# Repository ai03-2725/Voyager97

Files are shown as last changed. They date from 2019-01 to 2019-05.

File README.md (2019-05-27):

# Voyager97
A versatile, modern full-functionality keyboard PCB

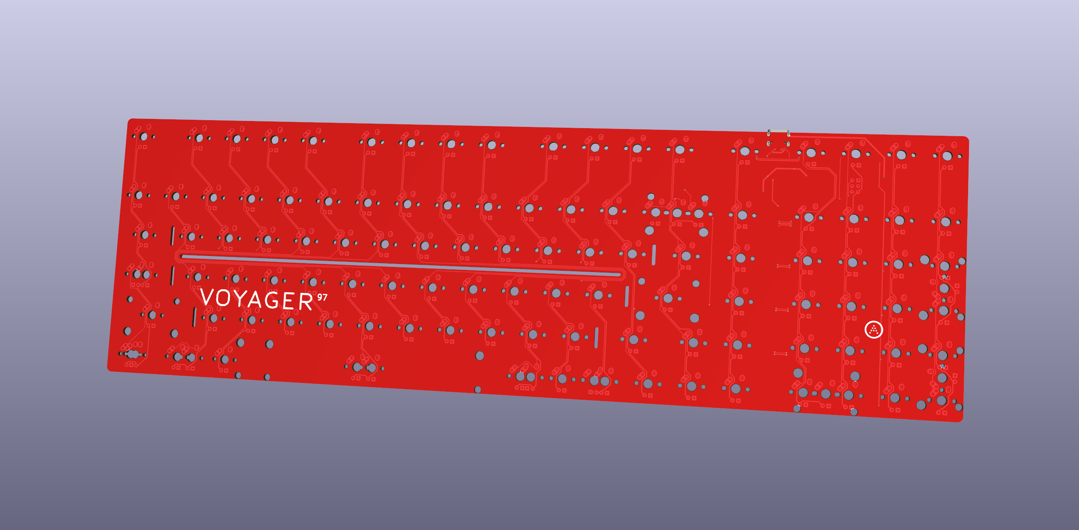
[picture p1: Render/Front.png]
Render

[PCB Layout](http://www.keyboard-layout-editor.com/#/gists/8a6f76a9ac2c94977268a77ed8a0af57)

#### In light of recent claims that I am 100% liable for any of my open source PCBs, I am adding this disclaimer.
#### I provide these PCBs as a reference for designing keyboard PCBs. Using them within your projects will require a will to do research of one's own and to learn the workings of them, potentially fixing issues if they exist.
# I provide these PCBs without liability and without any guarantees regarding functionality, as expressed in the MIT license under which all of these PCBs are licensed.

### Features
* In-switch LED backlighting
* RGB underglow
* Flex slot cutout for typing comfort
* Decent amount of layout compatibility
* Over-current and static discharge protection
* Fully open-source

### The Voyager PCB Family
The Voyager PCBs offer fully featured PCBs fit for any keyboard, whether mass production or high-end.

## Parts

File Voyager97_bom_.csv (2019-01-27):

Component | Description | Part | References | Value | Footprint | Quantity Per PCB | Datasheet | Field8 | Field4 | Field7 | Field6 | Field5
1 |  | MX-1U | BS1-2 BS2 MX_#0_1 MX_#1 MX_#2 MX_#3 MX_#4 MX_#5 MX_#6 MX_#7 MX_#8 MX_#9 MX_'1 MX_,1 MX_-1 MX_.1 MX_/1 MX_;1 MX_=1 MX_A1 MX_B1 MX_C1 MX_D1 MX_DOWN1 MX_E1 MX_ESC1 MX_EX1 MX_EX2 MX_EX3 MX_EX4 MX_F1 MX_FN1 MX_FN2 MX_FN3 MX_FN4 MX_FN5 MX_FN6 MX_FN7 MX_FN8 MX_FN9 MX_FN10 MX_FN11 MX_FN12 MX_G1 MX_H1 MX_I1 MX_J1 MX_K1 MX_L1 MX_LEFT1 MX_M1 MX_N1 MX_NUM1 MX_NUM2 MX_NUM3 MX_NUM4 MX_NUM5 MX_NUM6 MX_NUM7 MX_NUM8 MX_NUM9 MX_NUM10 MX_NUM11 MX_NUM12 MX_NUM13 MX_NUM14 MX_NUM15 MX_NUM16 MX_NUM17 MX_NUM18 MX_NUM19 MX_NUM20 MX_NUM21 MX_NUM22 MX_NUM23 MX_NUM24 MX_O1 MX_P1 MX_Q1 MX_R1 MX_RESET1 MX_RIGHT1 MX_S1 MX_T1 MX_U1 MX_UP1 MX_V1 MX_W1 MX_X1 MX_Y1 MX_Z1 MX_[1 MX_]1 MX_`1 | MX-1U | MX-1U | 94
2 |  | MX-2U | BS1-1 | MX-2U | MX-2U | 1
3 | Unpolarized capacitor | C_Small | C6 C7 C8 | 0.1uF | C_0603 | 3
4 | Unpolarized capacitor | C_Small | C2 C5 | 1uF | C_0603 | 2
5 | Unpolarized capacitor | C_Small | C3 C4 | 22pF | C_0603 | 2
6 |  | MX-1.25U | CL1-2 | MX-1.25U | MX-1.25U-FLIPPED | 1
7 |  | MX-1.75U | CL1-1 | MX-1.75U | MX-1.75U | 1
8 | Diode, small symbol | D_Small | D1 D2 D3 D4 D5 D6 D7 D8 D9 D10 D11 D12 D13 D14 D15 D16 D17 D18 D19 D20 D21 D22 D23 D24 D25 D26 D27 D28 D29 D30 D31 D32 D33 D35 D36 D37 D38 D39 D40 D41 D42 D43 D44 D45 D46 D47 D48 D52 D53 D54 D55 D56 D57 D58 D59 D60 D61 D62 D63 D65 D66 D67 D68 D69 D70 D71 D72 D73 D74 D75 D76 D77 D78 D80 D81 D82 D83 D84 D85 D86 D87 D89 D90 D91 D92 D93 D94 D95 D96 D97 D98 D99 D100 D101 D102 D103 D104 D105 D106 D107 D108 D109 D110 D111 D112 D113 D114 | SOD-323 | D_SOD-123 | 107
9 | resettable fuse, polymeric positive temperature coefficient (PPTC), small symbol | Polyfuse_Small | F1 | 500mA | Fuse_SMD1206_Reflow | 1
10 | Atmel 6-pin ISP connector | AVR-ISP-6 | J1 | AVR-ISP-6 | Reset_Pretty-Mask | 1 | ~
11 |  | MX-1U | LM1-1 | MX-1.25U | MX-1.25U | 1
12 |  | MX-1.25U | LM2-1 LM3-1 | MX-1.25U | MX-1.25U | 2
13 |  | MX-1.5U | LM1-2 RM1-2 RM3-2 | MX-1.5U | MX-1.5U-FLIPPED | 3
14 |  | MX-1.5U | LM3-2 MX_TAB1 MX_\1 | MX-1.5U | MX-1.5U | 3
15 |  | MX-2.25U | LS1-1 MX_RETURN1 | MX-2.25U | MX-2.25U | 2
16 |  | MX-1U | MX_RSHIFT1 | MX-1.75U | MX-1.75U | 1
17 |  | MX-1U | MX_NUMEXT2 MX_NUMEXT4 MX_NUMEXT5 | MX-2U | MX-2U-ReversedStabilizers | 3
18 | Transistor NPN (general) | Q_NPN_BCE | Q1 | DSS60601MZ4-13 | SOT-223-3_TabPin2 | 1
19 | Resistor, small symbol | R_Small | R1 R2 R3 R4 R5 R6 R7 R8 R9 R10 R11 R12 R13 R14 R15 R16 R17 R18 R19 R20 R21 R22 R23 R24 R25 R26 R27 R28 R29 R30 R31 R32 R33 R34 R35 R36 R37 R38 R39 R40 R41 R42 R43 R44 R45 R46 R47 R48 R49 R50 R52 R53 R54 R55 R56 R57 R58 R59 R60 R61 R62 R63 R65 R66 R67 R68 R69 R70 R71 R72 R73 R74 R75 R76 R77 R78 R80 R81 R82 R83 R84 R85 R86 R87 R89 R90 R91 R95 R96 R97 R98 R99 R100 R101 R102 R103 R104 R105 R106 R107 R108 R109 R110 R111 R112 R113 R114 RC4 | 1k | R_0603 | 108
20 | Resistor, small symbol | R_Small | RC5 | 1.5k | R_0603 | 1
21 | Resistor, small symbol | R_Small | RC3 | 10k | R_0603 | 1
22 | Resistor, small symbol | R_Small | RC1 RC2 | 22 | R_0603 | 2
23 | Resistor, small symbol | R_Small | RC6 RC7 | 5k1 | R_0603 | 2
24 |  | MX-1.25U | RM1-1 RM2-1 RM3-1 | MX-1U | MX-1U | 3
25 |  | MX-6.25U | SP1 | MX-6.25U | MX-6.25U-ReversedStabilizers | 1
26 |  | MX-7U | SP2 | MX-7U | MX-7U-ReversedStabilizers | 1
27 | Push button switch, generic, two pins | SW_Push | SW1 | SW_Push | SKQG-1155865 | 1
28 | 16MHz, 64kB Flash, 4kB SRAM, 2kB EEPROM, USB 2.0, QFN-64 | AT90USB1286-MU | U1 | AT90USB1286-AU | QFN-64-1EP_9x9mm_Pitch0.5mm | 1 | 8.69 USD | AT90USB1286-AU | TQFP-64 Microchip | Good | Embedded microcontroller AT90USB1286-AU TQFP 64 _14x14_ Microchip Technology 8-Bit 16 MHz I/O number 48 | Microchip
29 |  | PRTR5V0U2X | U2 | PRTR5V0U2X | SOT143B | 1
30 |  | HRO-TYPE-C-31-M-12 | USB1 | HRO-TYPE-C-31-M-12 | HRO-TYPE-C-31-M-12-Assembly | 1
31 | Four pin crystal (GND on pins 2 and 4), e.g. in SMD package | Crystal_GND24 | Y1 | 16MHz | Crystal_SMD_3225-4pin_3.2x2.5mm | 1
Component Groups: | 31
Component Count: | 353
Fitted Components: | 353
Number of PCBs: | 1
Total components: | 353
Schematic Version:
Schematic Date:
BoM Date: | 1/27/2019 3:01
Schematic Source:
KiCad Version: | Eeschema (5.0.0)

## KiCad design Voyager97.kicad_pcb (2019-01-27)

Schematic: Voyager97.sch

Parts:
C2, C5: 1uF; C_0603
C3, C4: 22pF; C_0603
C6, C7, C8: 0.1uF; C_0603
F1: 500mA; Fuse_SMD1206_Reflow
J1: AVR-ISP-6; Reset_Pretty-Mask
Q1: DSS60601MZ4-13; SOT-223-3_TabPin2
RC1, RC2: 22; R_0603
RC3: 10k; R_0603
RC4: 1k; R_0603
RC5: 1.5k; R_0603
RC6, RC7: 5k1; R_0603
SW1: SW_Push; SKQG-1155865
U1: AT90USB1286-AU; QFN-64-1EP_9x9mm_Pitch0.5mm
U2: PRTR5V0U2X; SOT143B
USB1: HRO-TYPE-C-31-M-12; HRO-TYPE-C-31-M-12-Assembly
Y1: 16MHz; Crystal_SMD_3225-4pin_3.2x2.5mm

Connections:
COL0: U1.61 (PF0); also elsewhere on the board
COL1: U1.60 (PF1); also elsewhere on the board
COL2: U1.59 (PF2); also elsewhere on the board
COL3: U1.58 (PF3); also elsewhere on the board
COL4: U1.57 (PF4); also elsewhere on the board
COL5: U1.56 (PF5); also elsewhere on the board
COL6: U1.55 (PF6); also elsewhere on the board
COL7: U1.54 (PF7); also elsewhere on the board
COL8: U1.51 (PA0); also elsewhere on the board
COL9: U1.50 (PA1); also elsewhere on the board
COL10: U1.49 (PA2); also elsewhere on the board
COL11: U1.48 (PA3); also elsewhere on the board
COL12: U1.47 (PA4); also elsewhere on the board
COL13: U1.46 (PA5); also elsewhere on the board
COL14: U1.45 (PA6); also elsewhere on the board
COL15: U1.36 (PC1); also elsewhere on the board
COL16: U1.35 (PC0); also elsewhere on the board
COL17: U1.34 (PE1); also elsewhere on the board
COL18: U1.33 (PE0); also elsewhere on the board
D+: RC2.2, U1.5 (D+)
D-: RC1.1, U1.4 (D-)
GND: C2.2, C3.2, C4.2, C5.1, C6.1, C7.1, C8.1, J1.6, Q1.3, RC4.2, RC6.1, RC7.1, SW1.1, U1.6 (UGND), U1.22 (GND), U1.53 (GND), U1.63 (GND), U1.65 (GND), U2.1, USB1.1, USB1.12, USB1.13, Y1.2, Y1.4
LEDGND: Q1.2; also elsewhere on the board
MISO: J1.1, U1.13 (PB3)
MOSI: J1.4, U1.12 (PB2)
unnamed: C2.1, U1.7 (UCAP)
unnamed: Q1.1, RC5.2
unnamed: RC1.2, U2.3, USB1.5, USB1.7
unnamed: RC2.1, U2.2, USB1.6, USB1.8
unnamed: RC4.1, U1.43 (PE2/~HWB)
unnamed: RC5.1, U1.17 (PB7)
unnamed: RC6.2, USB1.4
unnamed: RC7.2, USB1.10
RESET: J1.5, RC3.2, SW1.2, U1.20 (~RESET)
ROW0: U1.32 (PD7); also elsewhere on the board
ROW1: U1.38 (PC3); also elsewhere on the board
ROW2: U1.39 (PC4); also elsewhere on the board
ROW3: U1.40 (PC5); also elsewhere on the board
ROW4: U1.41 (PC6); also elsewhere on the board
ROW5: U1.42 (PC7); also elsewhere on the board
SCK: J1.3, U1.11 (PB1)
VCC: F1.2, U2.4, USB1.2, USB1.11
XTAL1: C3.1, U1.24 (XTAL1), Y1.1
XTAL2: C4.1, U1.23 (XTAL2), Y1.3

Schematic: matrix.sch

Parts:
BS1-1: MX-2U
BS1-2, BS2: MX-1U
CL1-1: MX-1.75U
CL1-2: MX-1.25U; MX-1.25U-FLIPPED
D1, D2, D3, D4, D5, D6, D7, D8, D9, D10, D11, D12, D13, D14, D15, D16, D17, D18, D19, D20, D21, D22, D23, D24, D25, D26, D27, D28, D29, D30, D31, D32, D33, D35, D36, D37, D38, D39, D40, D41, D42, D43, D44, D45, D46, D47, D48, D52, D53, D54, D55, D56, D57, D58, D59, D60, D61, D62, D63, D65, D66, D67, D68, D69, D70, D71, D72, D73, D74, D75, D76, D77, D78, D80, D81, D82, D83, D84, D85, D86, D87, D89, D90, D91, D92, D93, D94, D95, D96, D97, D98, D99, D100, D101, D102, D103, D104, D105, D106, D107, D108, D109, D110, D111, D112, D113, D114: SOD-323; D_SOD-123
LM1-1, LM2-1, LM3-1: MX-1.25U
LM1-2: MX-1.5U; MX-1.5U-FLIPPED
LM3-2: MX-1.5U
LS1-1: MX-2.25U
MX_#0_1, MX_#1, MX_#2, MX_#3, MX_#4, MX_#5, MX_#6, MX_#7, MX_#8, MX_#9: MX-1U
MX_'1: MX-1U
MX_,1: MX-1U
MX_-1: MX-1U
MX_.1: MX-1U
MX_/1: MX-1U
MX_;1: MX-1U
MX_=1: MX-1U
MX_A1: MX-1U
MX_B1: MX-1U
MX_C1: MX-1U
MX_D1: MX-1U
MX_DOWN1: MX-1U
MX_E1: MX-1U
MX_ESC1: MX-1U
MX_EX1, MX_EX2, MX_EX3, MX_EX4: MX-1U
MX_F1: MX-1U
MX_FN1, MX_FN2, MX_FN3, MX_FN4, MX_FN5, MX_FN6, MX_FN7, MX_FN8, MX_FN9, MX_FN10, MX_FN11, MX_FN12: MX-1U
MX_G1: MX-1U
MX_H1: MX-1U
MX_I1: MX-1U
MX_J1: MX-1U
MX_K1: MX-1U
MX_L1: MX-1U
MX_LEFT1: MX-1U
MX_M1: MX-1U
MX_N1: MX-1U
MX_NUM1, MX_NUM2, MX_NUM3, MX_NUM4, MX_NUM5, MX_NUM6, MX_NUM7, MX_NUM8, MX_NUM9, MX_NUM10, MX_NUM11, MX_NUM12, MX_NUM13, MX_NUM14, MX_NUM15, MX_NUM16, MX_NUM17, MX_NUM18, MX_NUM19, MX_NUM20, MX_NUM21, MX_NUM22, MX_NUM23, MX_NUM24: MX-1U
MX_NUMEXT2, MX_NUMEXT4, MX_NUMEXT5: MX-2U; MX-2U-ReversedStabilizers
MX_O1: MX-1U
MX_P1: MX-1U
MX_Q1: MX-1U
MX_R1: MX-1U
MX_RESET1: MX-1U
MX_RETURN1: MX-2.25U
MX_RIGHT1: MX-1U
MX_RSHIFT1: MX-1.75U
MX_S1: MX-1U
MX_T1: MX-1U
MX_TAB1: MX-1.5U
MX_U1: MX-1U
MX_UP1: MX-1U
MX_V1: MX-1U
MX_W1: MX-1U
MX_X1: MX-1U
MX_Y1: MX-1U
MX_Z1: MX-1U
MX_[1: MX-1U
MX_\1: MX-1.5U
MX_]1: MX-1U
MX_`1: MX-1U
R1, R2, R3, R4, R5, R6, R7, R8, R9, R10, R11, R12, R13, R14, R15, R16, R17, R18, R19, R20, R21, R22, R23, R24, R25, R26, R27, R28, R29, R30, R31, R32, R33, R34, R35, R36, R37, R38, R39, R40, R41, R42, R43, R44, R45, R46, R47, R48, R49, R50, R52, R53, R54, R55, R56, R57, R58, R59, R60, R61, R62, R63, R65, R66, R67, R68, R69, R70, R71, R72, R73, R74, R75, R76, R77, R78, R80, R81, R82, R83, R84, R85, R86, R87, R89, R90, R91, R95, R96, R97, R98, R99, R100, R101, R102, R103, R104, R105, R106, R107, R108, R109, R110, R111, R112, R113, R114: 1k; R_0603
RM1-1, RM2-1, RM3-1: MX-1U
RM1-2, RM3-2: MX-1.5U; MX-1.5U-FLIPPED
SP1: MX-6.25U; MX-6.25U-ReversedStabilizers
SP2: MX-7U; MX-7U-ReversedStabilizers

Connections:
COL0: CL1-1.1, CL1-2.2, LM1-1.1, LM1-2.1, LS1-1.1, MX_ESC1.1, MX_TAB1.1, MX_`1.1; also elsewhere on the board
COL1: LM2-1.1, LM3-2.2, MX_#1.1, MX_A1.1, MX_Q1.1, MX_Z1.1; also elsewhere on the board
COL2: LM3-1.1, MX_#2.1, MX_FN1.1, MX_S1.1, MX_W1.1, MX_X1.1; also elsewhere on the board
COL3: MX_#3.1, MX_C1.1, MX_D1.1, MX_E1.1, MX_FN2.1; also elsewhere on the board
COL4: MX_#4.1, MX_F1.1, MX_FN3.1, MX_R1.1, MX_V1.1; also elsewhere on the board
COL5: MX_#5.1, MX_B1.1, MX_FN4.1, MX_G1.1, MX_T1.1, SP1.1, SP2.2; also elsewhere on the board
COL6: MX_#6.1, MX_FN5.1, MX_H1.1, MX_N1.1, MX_Y1.1; also elsewhere on the board
COL7: MX_#7.1, MX_FN6.1, MX_J1.1, MX_M1.1, MX_U1.1; also elsewhere on the board
COL8: MX_#8.1, MX_,1.1, MX_FN7.1, MX_I1.1, MX_K1.1; also elsewhere on the board
COL9: MX_#9.1, MX_.1.1, MX_FN8.1, MX_L1.1, MX_O1.1, RM1-1.1, RM1-2.2; also elsewhere on the board
COL10: MX_#0_1.1, MX_/1.1, MX_;1.1, MX_FN9.1, MX_P1.1, RM2-1.1; also elsewhere on the board
COL11: MX_'1.1, MX_-1.1, MX_FN10.1, MX_[1.1, RM3-1.1, RM3-2.2; also elsewhere on the board
COL12: BS2.1, MX_=1.1, MX_FN11.1, MX_LEFT1.1, MX_RSHIFT1.1, MX_]1.1; also elsewhere on the board
COL13: BS1-1.1, BS1-2.1, MX_DOWN1.1, MX_FN12.1, MX_RETURN1.1, MX_UP1.1, MX_\1.1; also elsewhere on the board
COL14: MX_EX1.1, MX_EX2.1, MX_EX3.1, MX_EX4.1, MX_RESET1.1, MX_RIGHT1.1; also elsewhere on the board
COL15: MX_NUM1.1, MX_NUM4.1, MX_NUM8.1, MX_NUM12.1, MX_NUM16.1, MX_NUM20.1, MX_NUMEXT5.1; also elsewhere on the board
COL16: MX_NUM2.1, MX_NUM5.1, MX_NUM9.1, MX_NUM13.1, MX_NUM17.1, MX_NUM21.1; also elsewhere on the board
COL17: MX_NUM3.1, MX_NUM6.1, MX_NUM10.1, MX_NUM14.1, MX_NUM18.1, MX_NUM22.1; also elsewhere on the board
COL18: MX_NUM7.1, MX_NUM11.1, MX_NUM15.1, MX_NUM19.1, MX_NUM23.1, MX_NUM24.1, MX_NUMEXT2.1, MX_NUMEXT4.1; also elsewhere on the board
LEDGND: R1.2, R2.2, R3.2, R4.2, R5.2, R6.2, R7.2, R8.2, R9.2, R10.2, R11.2, R12.2, R13.2, R14.2, R15.2, R16.2, R17.2, R18.2, R19.2, R20.2, R21.2, R22.2, R23.2, R24.2, R25.2, R26.2, R27.2, R28.2, R29.2, R30.2, R31.2, R32.2, R33.2, R34.2, R35.2, R36.2, R37.2, R38.2, R39.2, R40.2, R41.2, R42.2, R43.2, R44.2, R45.2, R46.2, R47.2, R48.2, R49.2, R50.2, R52.2, R53.2, R54.2, R55.2, R56.2, R57.2, R58.2, R59.2, R60.2, R61.2, R62.2, R63.2, R65.2, R66.2, R67.2, R68.2, R69.2, R70.2, R71.2, R72.2, R73.2, R74.2, R75.2, R76.2, R77.2, R78.2, R80.2, R81.2, R82.2, R83.2, R84.2, R85.2, R86.2, R87.2, R89.2, R90.2, R91.2, R95.2, R96.2, R97.2, R98.2, R99.2, R100.2, R101.2, R102.2, R103.2, R104.2, R105.2, R106.2, R107.2, R108.2, R109.2, R110.2, R111.2, R112.2, R113.2, R114.2; also elsewhere on the board
unnamed: BS1-1.2, BS1-2.2, D30.2
unnamed: BS1-1.4, BS1-2.4, R30.1
unnamed: BS2.2, D31.2
unnamed: BS2.4, R31.1
unnamed: CL1-1.2, CL1-2.1, D52.2
unnamed: CL1-1.4, CL1-2.4, R52.1
unnamed: D1.2, MX_ESC1.2
unnamed: D2.2, MX_FN1.2
unnamed: D3.2, MX_FN2.2
unnamed: D4.2, MX_FN3.2
unnamed: D5.2, MX_FN4.2
unnamed: D6.2, MX_FN5.2
unnamed: D7.2, MX_FN6.2
unnamed: D8.2, MX_FN7.2
unnamed: D9.2, MX_FN8.2
unnamed: D10.2, MX_FN9.2
unnamed: D11.2, MX_FN10.2
unnamed: D12.2, MX_FN11.2
unnamed: D13.2, MX_FN12.2
unnamed: D14.2, MX_EX1.2
unnamed: D15.2, MX_RESET1.2
unnamed: D16.2, MX_NUM24.2
unnamed: D17.2, MX_`1.2
unnamed: D18.2, MX_#1.2
unnamed: D19.2, MX_#2.2
unnamed: D20.2, MX_#3.2
unnamed: D21.2, MX_#4.2
unnamed: D22.2, MX_#5.2
unnamed: D23.2, MX_#6.2
unnamed: D24.2, MX_#7.2
unnamed: D25.2, MX_#8.2
unnamed: D26.2, MX_#9.2
unnamed: D27.2, MX_#0_1.2
unnamed: D28.2, MX_-1.2
unnamed: D29.2, MX_=1.2
unnamed: D32.2, MX_EX2.2
unnamed: D33.2, MX_EX3.2
unnamed: D35.2, MX_TAB1.2
unnamed: D36.2, MX_Q1.2
unnamed: D37.2, MX_W1.2
unnamed: D38.2, MX_E1.2
unnamed: D39.2, MX_R1.2
unnamed: D40.2, MX_T1.2
unnamed: D41.2, MX_Y1.2
unnamed: D42.2, MX_U1.2
unnamed: D43.2, MX_I1.2
unnamed: D44.2, MX_O1.2
unnamed: D45.2, MX_P1.2
unnamed: D46.2, MX_[1.2
unnamed: D47.2, MX_]1.2
unnamed: D48.2, MX_\1.2
unnamed: D53.2, MX_A1.2
unnamed: D54.2, MX_S1.2
unnamed: D55.2, MX_D1.2
unnamed: D56.2, MX_F1.2
unnamed: D57.2, MX_G1.2
unnamed: D58.2, MX_H1.2
unnamed: D59.2, MX_J1.2
unnamed: D60.2, MX_K1.2
unnamed: D61.2, MX_L1.2
unnamed: D62.2, MX_;1.2
unnamed: D63.2, MX_'1.2
unnamed: D65.2, MX_RETURN1.2
unnamed: D66.2, MX_UP1.2
unnamed: D67.2, LS1-1.2
unnamed: D68.2, MX_Z1.2
unnamed: D69.2, MX_X1.2
unnamed: D70.2, MX_C1.2
unnamed: D71.2, MX_V1.2
unnamed: D72.2, MX_B1.2
unnamed: D73.2, MX_N1.2
unnamed: D74.2, MX_M1.2
unnamed: D75.2, MX_,1.2
unnamed: D76.2, MX_.1.2
unnamed: D77.2, MX_/1.2
unnamed: D78.2, MX_RSHIFT1.2
unnamed: D80.2, MX_EX4.2
unnamed: D81.2, MX_LEFT1.2
unnamed: D82.2, MX_DOWN1.2
unnamed: D83.2, MX_RIGHT1.2
unnamed: D84.2, LM1-1.2, LM1-2.2
unnamed: D85.2, LM2-1.2, LM3-2.1
unnamed: D86.2, LM3-1.2
unnamed: D87.2, SP1.2, SP2.1
unnamed: D89.2, RM1-1.2, RM1-2.1
unnamed: D90.2, RM2-1.2
unnamed: D91.2, RM3-1.2, RM3-2.1
unnamed: D92.2, MX_NUM1.2
unnamed: D93.2, MX_NUM2.2
unnamed: D94.2, MX_NUM3.2
unnamed: D95.2, MX_NUM4.2
unnamed: D96.2, MX_NUM5.2
unnamed: D97.2, MX_NUM6.2
unnamed: D98.2, MX_NUM7.2
unnamed: D99.2, MX_NUM8.2
unnamed: D100.2, MX_NUM9.2
unnamed: D101.2, MX_NUM10.2
unnamed: D102.2, MX_NUM11.2, MX_NUMEXT2.2
unnamed: D103.2, MX_NUM12.2
unnamed: D104.2, MX_NUM13.2
unnamed: D105.2, MX_NUM14.2
unnamed: D106.2, MX_NUM15.2
unnamed: D107.2, MX_NUM16.2
unnamed: D108.2, MX_NUM17.2
unnamed: D109.2, MX_NUM18.2
unnamed: D110.2, MX_NUM19.2, MX_NUMEXT4.2
unnamed: D111.2, MX_NUM20.2, MX_NUMEXT5.2
unnamed: D112.2, MX_NUM21.2
unnamed: D113.2, MX_NUM22.2
unnamed: D114.2, MX_NUM23.2
unnamed: LM1-1.4, LM1-2.4, R84.1
unnamed: LM2-1.4, LM3-2.4, R85.1
unnamed: LM3-1.4, R86.1
unnamed: LS1-1.4, R67.1
unnamed: MX_#0_1.4, R27.1
unnamed: MX_#1.4, R18.1
unnamed: MX_#2.4, R19.1
unnamed: MX_#3.4, R20.1
unnamed: MX_#4.4, R21.1
unnamed: MX_#5.4, R22.1
unnamed: MX_#6.4, R23.1
unnamed: MX_#7.4, R24.1
unnamed: MX_#8.4, R25.1
unnamed: MX_#9.4, R26.1
unnamed: MX_'1.4, R63.1
unnamed: MX_,1.4, R75.1
unnamed: MX_-1.4, R28.1
unnamed: MX_.1.4, R76.1
unnamed: MX_/1.4, R77.1
unnamed: MX_;1.4, R62.1
unnamed: MX_=1.4, R29.1
unnamed: MX_A1.4, R53.1
unnamed: MX_B1.4, R72.1
unnamed: MX_C1.4, R70.1
unnamed: MX_D1.4, R55.1
unnamed: MX_DOWN1.4, R82.1
unnamed: MX_E1.4, R38.1
unnamed: MX_ESC1.4, R1.1
unnamed: MX_EX1.4, R14.1
unnamed: MX_EX2.4, R49.1
unnamed: MX_EX3.4, R50.1
unnamed: MX_EX4.4, R80.1
unnamed: MX_F1.4, R56.1
unnamed: MX_FN1.4, R2.1
unnamed: MX_FN2.4, R3.1
unnamed: MX_FN3.4, R4.1
unnamed: MX_FN4.4, R5.1
unnamed: MX_FN5.4, R6.1
unnamed: MX_FN6.4, R7.1
unnamed: MX_FN7.4, R8.1
unnamed: MX_FN8.4, R9.1
unnamed: MX_FN9.4, R10.1
unnamed: MX_FN10.4, R11.1
unnamed: MX_FN11.4, R12.1
unnamed: MX_FN12.4, R13.1
unnamed: MX_G1.4, R57.1
unnamed: MX_H1.4, R58.1
unnamed: MX_I1.4, R43.1
unnamed: MX_J1.4, R59.1
unnamed: MX_K1.4, R60.1
unnamed: MX_L1.4, R61.1
unnamed: MX_LEFT1.4, R81.1
unnamed: MX_M1.4, R74.1
unnamed: MX_N1.4, R73.1
unnamed: MX_NUM1.4, R16.1
unnamed: MX_NUM2.4, R32.1
unnamed: MX_NUM3.4, R33.1
unnamed: MX_NUM4.4, R95.1
unnamed: MX_NUM5.4, R96.1
unnamed: MX_NUM6.4, R97.1
unnamed: MX_NUM7.4, R98.1
unnamed: MX_NUM8.4, R99.1
unnamed: MX_NUM9.4, R100.1
unnamed: MX_NUM10.4, R101.1
unnamed: MX_NUM11.4, MX_NUMEXT2.4, R102.1
unnamed: MX_NUM12.4, R103.1
unnamed: MX_NUM13.4, R104.1
unnamed: MX_NUM14.4, R105.1
unnamed: MX_NUM15.4, R106.1
unnamed: MX_NUM16.4, R107.1
unnamed: MX_NUM17.4, R108.1
unnamed: MX_NUM18.4, R109.1
unnamed: MX_NUM19.4, MX_NUMEXT4.4, R110.1
unnamed: MX_NUM20.4, MX_NUMEXT5.4, R111.1
unnamed: MX_NUM21.4, R112.1
unnamed: MX_NUM22.4, R113.1
unnamed: MX_NUM23.4, R114.1
unnamed: MX_NUM24.4, R34.1
unnamed: MX_O1.4, R44.1
unnamed: MX_P1.4, R45.1
unnamed: MX_Q1.4, R36.1
unnamed: MX_R1.4, R39.1
unnamed: MX_RESET1.4, R15.1
unnamed: MX_RETURN1.4, R65.1
unnamed: MX_RIGHT1.4, R83.1
unnamed: MX_RSHIFT1.4, R78.1
unnamed: MX_S1.4, R54.1
unnamed: MX_T1.4, R40.1
unnamed: MX_TAB1.4, R35.1
unnamed: MX_U1.4, R42.1
unnamed: MX_UP1.4, R66.1
unnamed: MX_V1.4, R71.1
unnamed: MX_W1.4, R37.1
unnamed: MX_X1.4, R69.1
unnamed: MX_Y1.4, R41.1
unnamed: MX_Z1.4, R68.1
unnamed: MX_[1.4, R46.1
unnamed: MX_\1.4, R48.1
unnamed: MX_]1.4, R47.1
unnamed: MX_`1.4, R17.1
unnamed: R87.1, SP1.4, SP2.4
unnamed: R89.1, RM1-1.4, RM1-2.4
unnamed: R90.1, RM2-1.4
unnamed: R91.1, RM3-1.4, RM3-2.4
ROW0: D1.1, D2.1, D3.1, D4.1, D5.1, D6.1, D7.1, D8.1, D9.1, D10.1, D11.1, D12.1, D13.1, D15.1, D16.1, D92.1, D93.1, D94.1; also elsewhere on the board
ROW1: D14.1, D17.1, D18.1, D19.1, D20.1, D21.1, D22.1, D23.1, D24.1, D25.1, D26.1, D27.1, D28.1, D29.1, D30.1, D95.1, D96.1, D97.1, D98.1; also elsewhere on the board
ROW2: D32.1, D35.1, D36.1, D37.1, D38.1, D39.1, D40.1, D41.1, D42.1, D43.1, D44.1, D45.1, D46.1, D47.1, D48.1, D99.1, D100.1, D101.1, D102.1; also elsewhere on the board
ROW3: D31.1, D33.1, D52.1, D53.1, D54.1, D55.1, D56.1, D57.1, D58.1, D59.1, D60.1, D61.1, D62.1, D63.1, D65.1, D103.1, D104.1, D105.1, D106.1; also elsewhere on the board
ROW4: D66.1, D67.1, D68.1, D69.1, D70.1, D71.1, D72.1, D73.1, D74.1, D75.1, D76.1, D77.1, D78.1, D80.1, D107.1, D108.1, D109.1, D110.1; also elsewhere on the board
ROW5: D81.1, D82.1, D83.1, D84.1, D85.1, D86.1, D87.1, D89.1, D90.1, D91.1, D111.1, D112.1, D113.1, D114.1; also elsewhere on the board

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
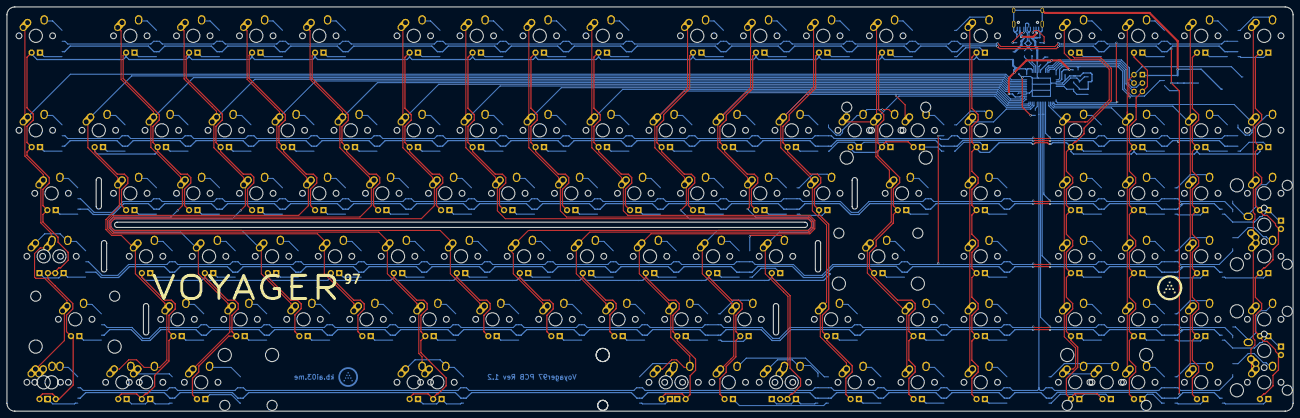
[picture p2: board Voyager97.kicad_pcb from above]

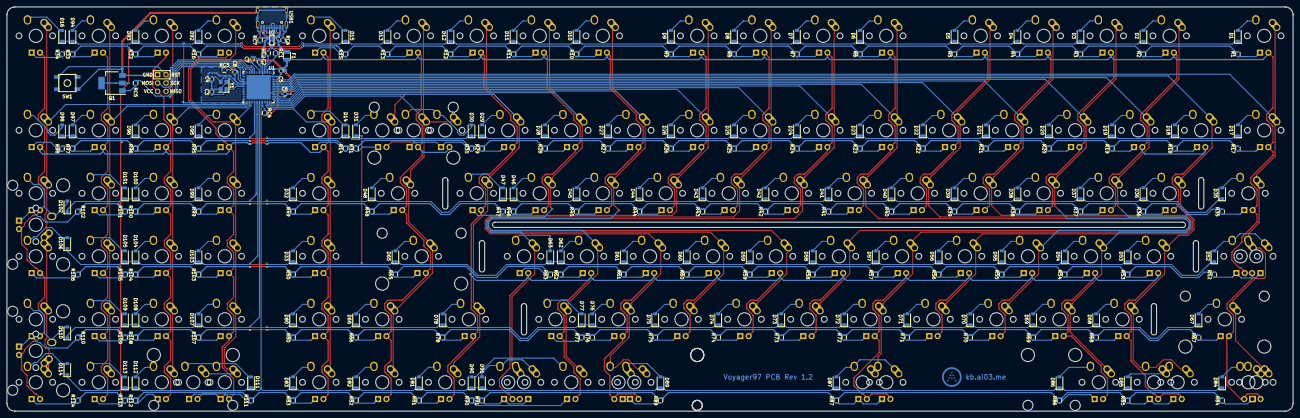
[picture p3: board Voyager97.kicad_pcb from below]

Board: 2 copper layers, 388.9 x 122.2 mm, 353 parts (236 on the bottom side), 259 nets.

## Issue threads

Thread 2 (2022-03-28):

Question about turning this PCB into an actual keyboard

sixtyfive, 2022-03-28:
Hi, I'm looking to build either a 100% keyboard or something a bit smaller. The V97 PCB looks like it could end up being my ticket. Unfortunately I can't find any build logs for it or even just photos of it or one of its siblings. What I have in mind is as simple as possible of a "sandwhich" of alu baseplate - some kind of foam for dampening - PCB - alu plate on top, with the alu plates being pressed against each other with screws, and then some rubber feet on the bottom. Do you think that's a build that could be possible with the Voyager 97 or is it just not made for that?

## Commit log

2018-11-09 Paste in project files from private files
    [Voyager97.kicad_pcb, Voyager97.sch, matrix.sch]
2018-11-09 Generate production data
    [Voyager97-B.Cu.gbl, Voyager97-B.Mask.gbs, Voyager97-B.Paste.gbp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]
2018-11-18 Routing tweaks
    [Voyager97-B.Cu.gbl, Voyager97-B.Mask.gbs, Voyager97-B.Paste.gbp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]
2018-11-24 Add flex cut in center
    [Voyager97.kicad_pcb]
2018-11-24 Add more flex cutouts
    [Voyager97.kicad_pcb, Voyager97.sch]
2018-11-25 Adjust cutout location for durability
    [Voyager97.kicad_pcb]
2018-11-27 Optimizations
    - Crystal placement
    - Tracks near SPI header
    [Voyager97.kicad_pcb]
2018-11-27 Reposition decoupling capacitor for greater effectiveness
    [Voyager97.kicad_pcb]
2018-11-29 Locallib doesn't even contain amtra's footprints anymore
    [Voyager97.kicad_pcb]
2019-01-27 Update to new universal logo
    [Voyager97-B.Cu.gbl, Voyager97-B.Mask.gbs, Voyager97-B.Paste.gbp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]
